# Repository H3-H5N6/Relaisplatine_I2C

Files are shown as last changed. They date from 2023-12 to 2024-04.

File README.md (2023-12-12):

# Beschreibung

8-fach Relaisplatine, die über I²C angesteuert wird. Die Relais werden dabei über eine separate Spannung versorgt.

Die I²C-Adresse muss durch entsprechende Brücken bei A0 - bis A2 ausgeält werden. Die Grundadresse des PCF 8475 ist 0x40 und de
ie des PCF 8475 ist 0x70.

Die LEDs bei den Relais leuchten, wenn die Relais in Ruhe sind. Des weiteren gibt es zwei Power-LEDs, einmal für die 5V vom I²C und einaml für die 5/12V der Relais.

Der Interrupt-Pin ist herausgezogen, aber nicht weiter beschaltet.

# Schaltplan

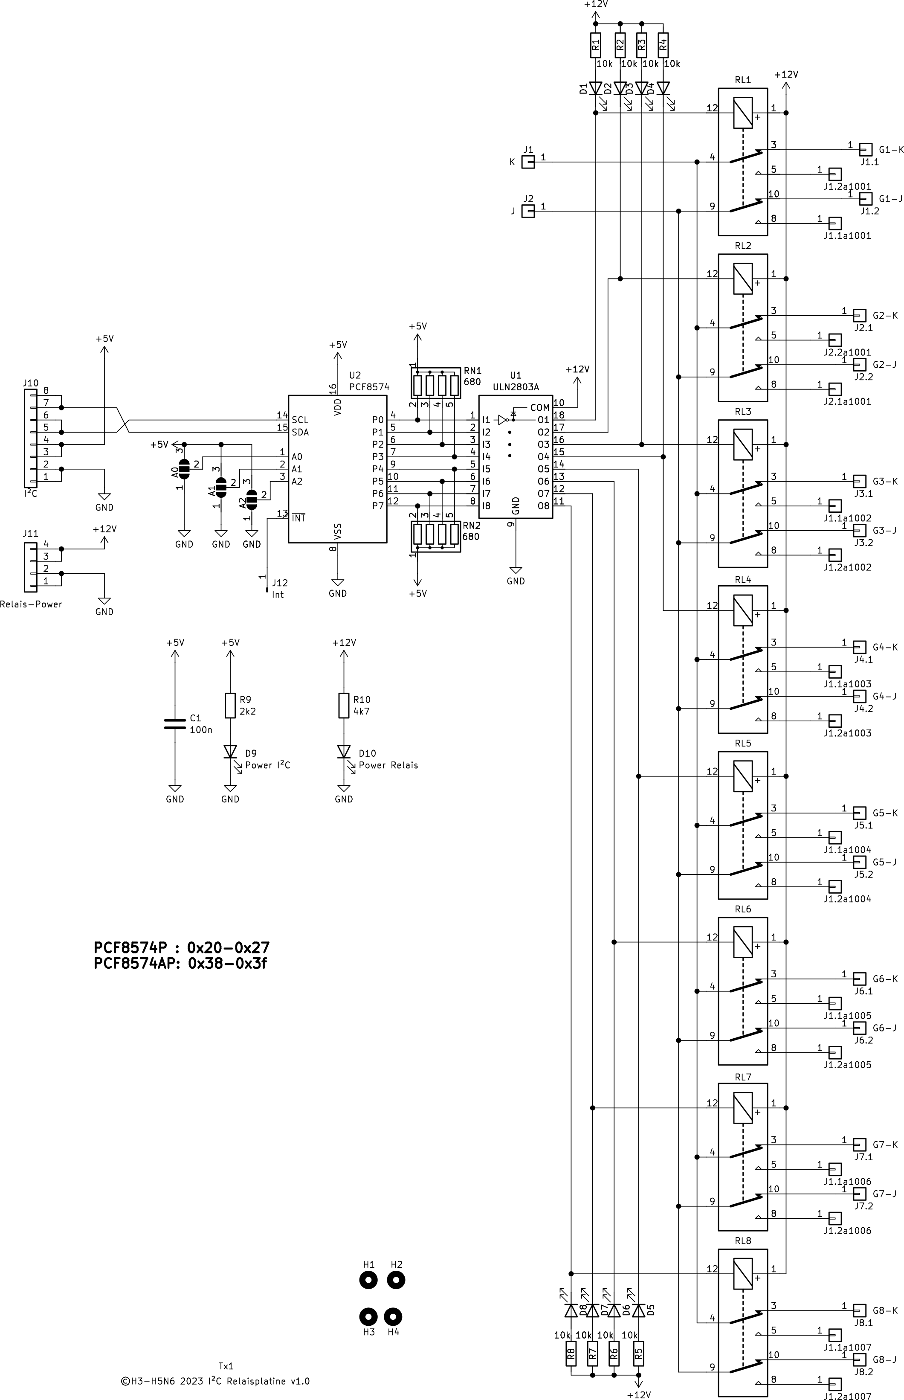
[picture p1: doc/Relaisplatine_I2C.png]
Schaltplan


# Bestückungsplan

Bestückungsplan

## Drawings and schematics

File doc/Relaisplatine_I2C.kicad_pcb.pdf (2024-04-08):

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

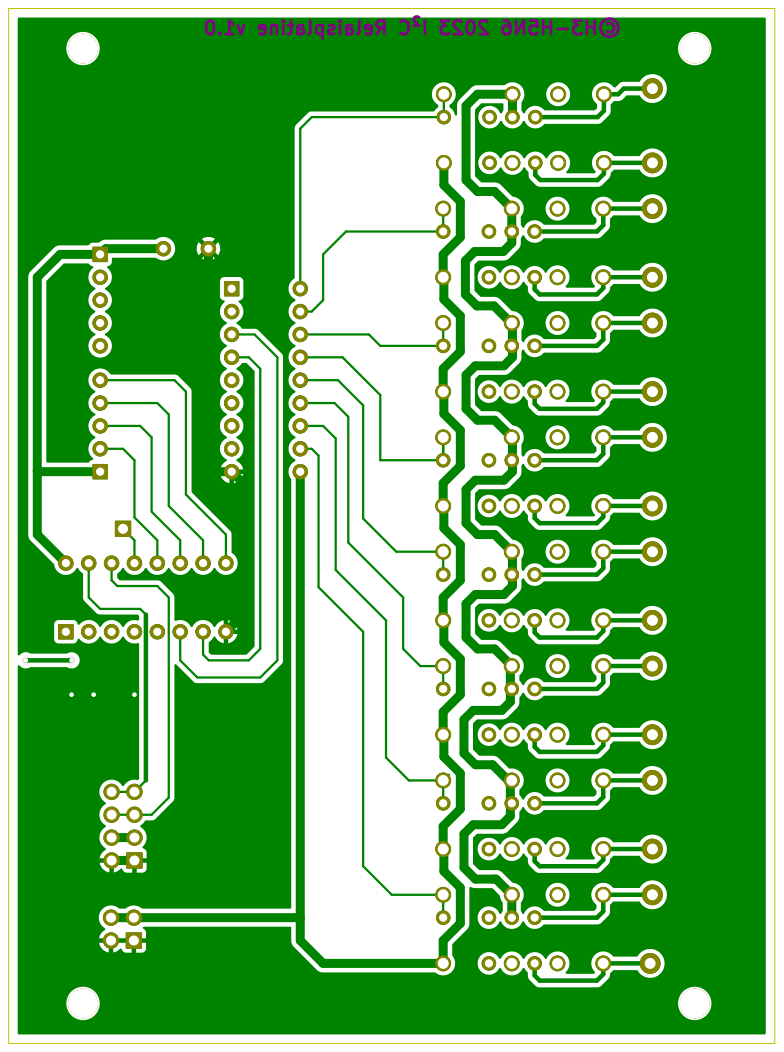
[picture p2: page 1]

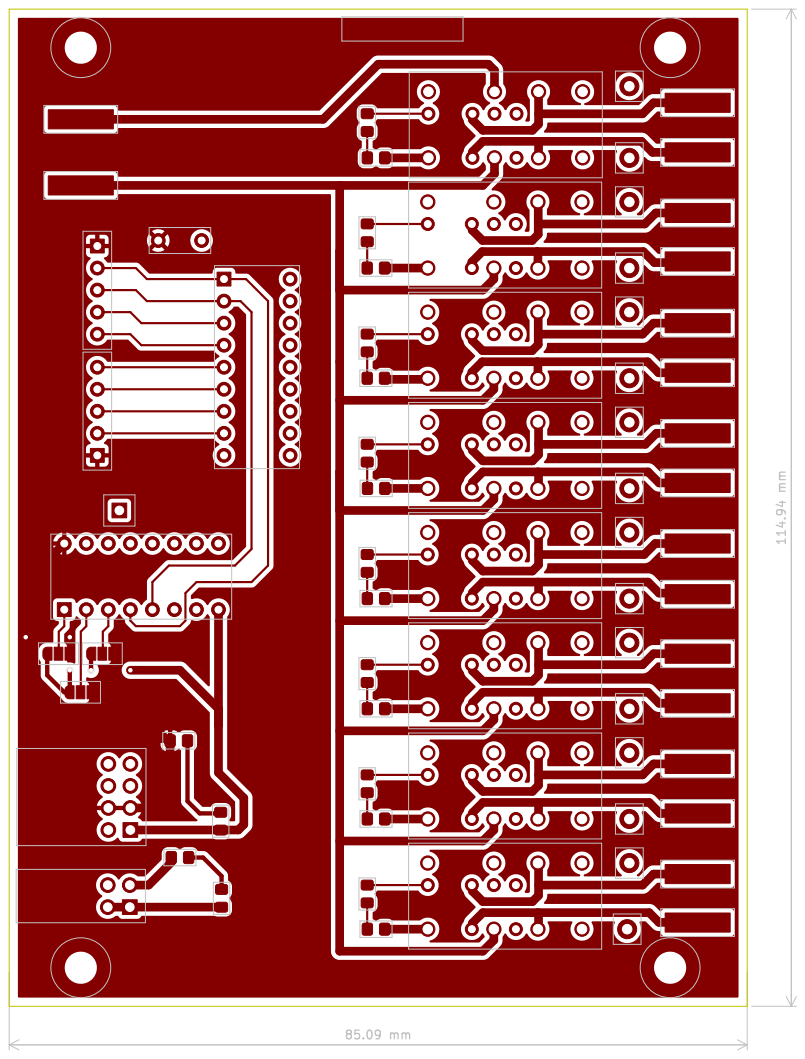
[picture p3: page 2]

# GND GND G5 G2 Relais stromlos G1 G8

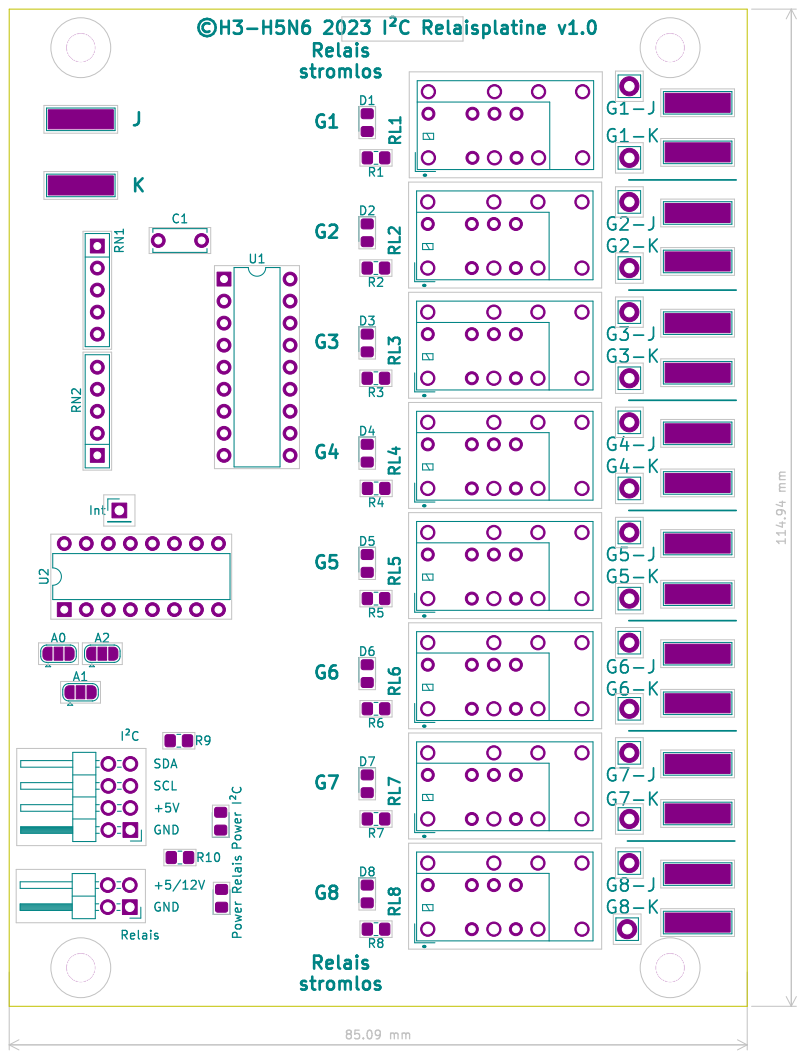
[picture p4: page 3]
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

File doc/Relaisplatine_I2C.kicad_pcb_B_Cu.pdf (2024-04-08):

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



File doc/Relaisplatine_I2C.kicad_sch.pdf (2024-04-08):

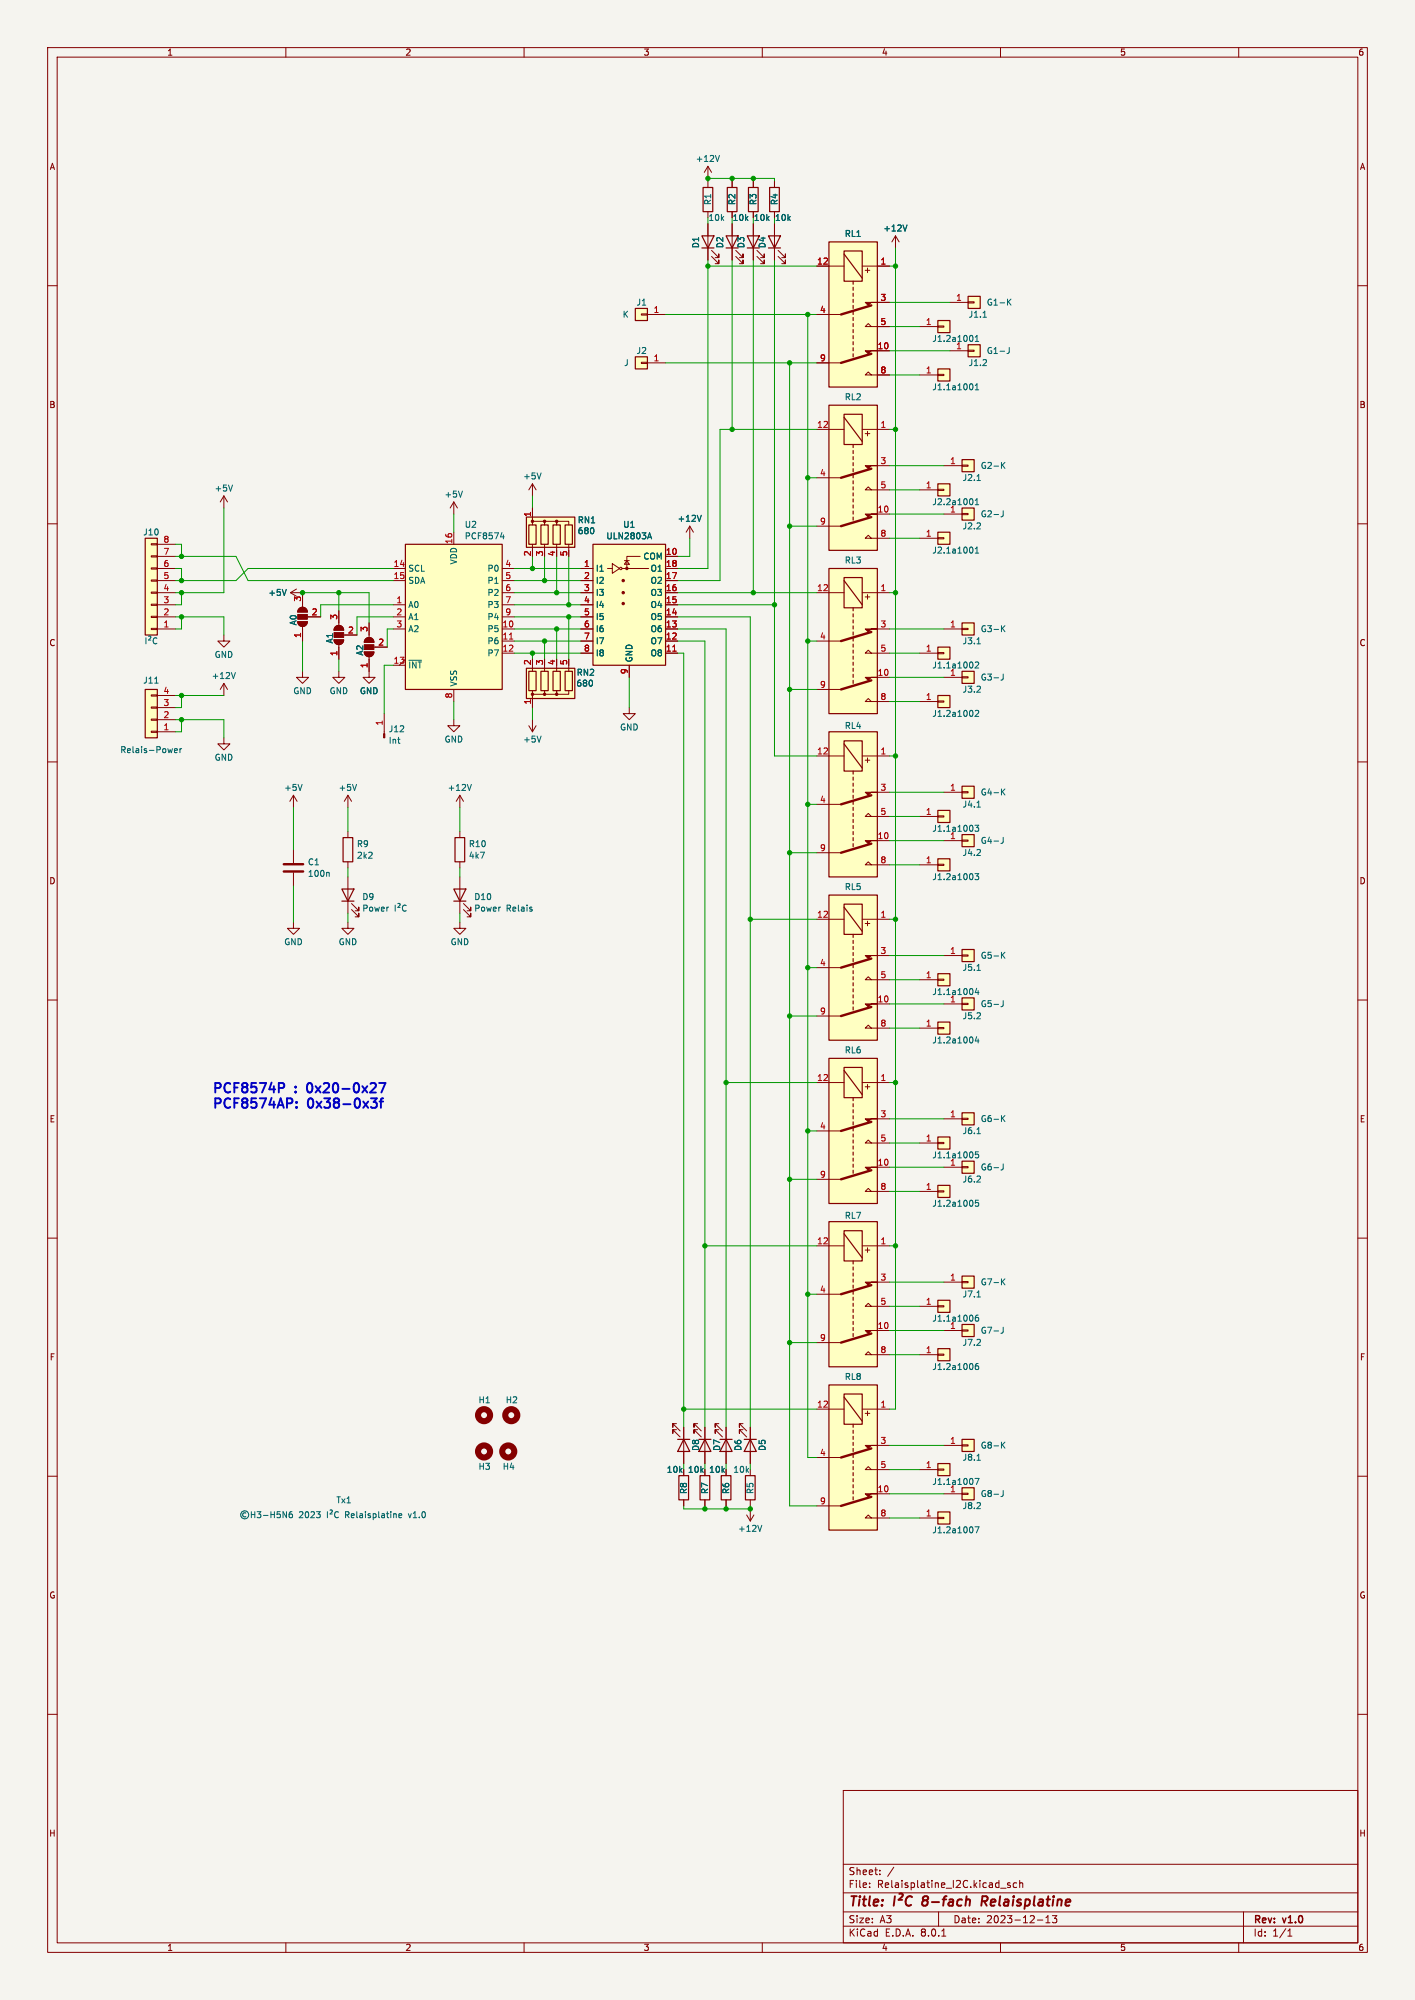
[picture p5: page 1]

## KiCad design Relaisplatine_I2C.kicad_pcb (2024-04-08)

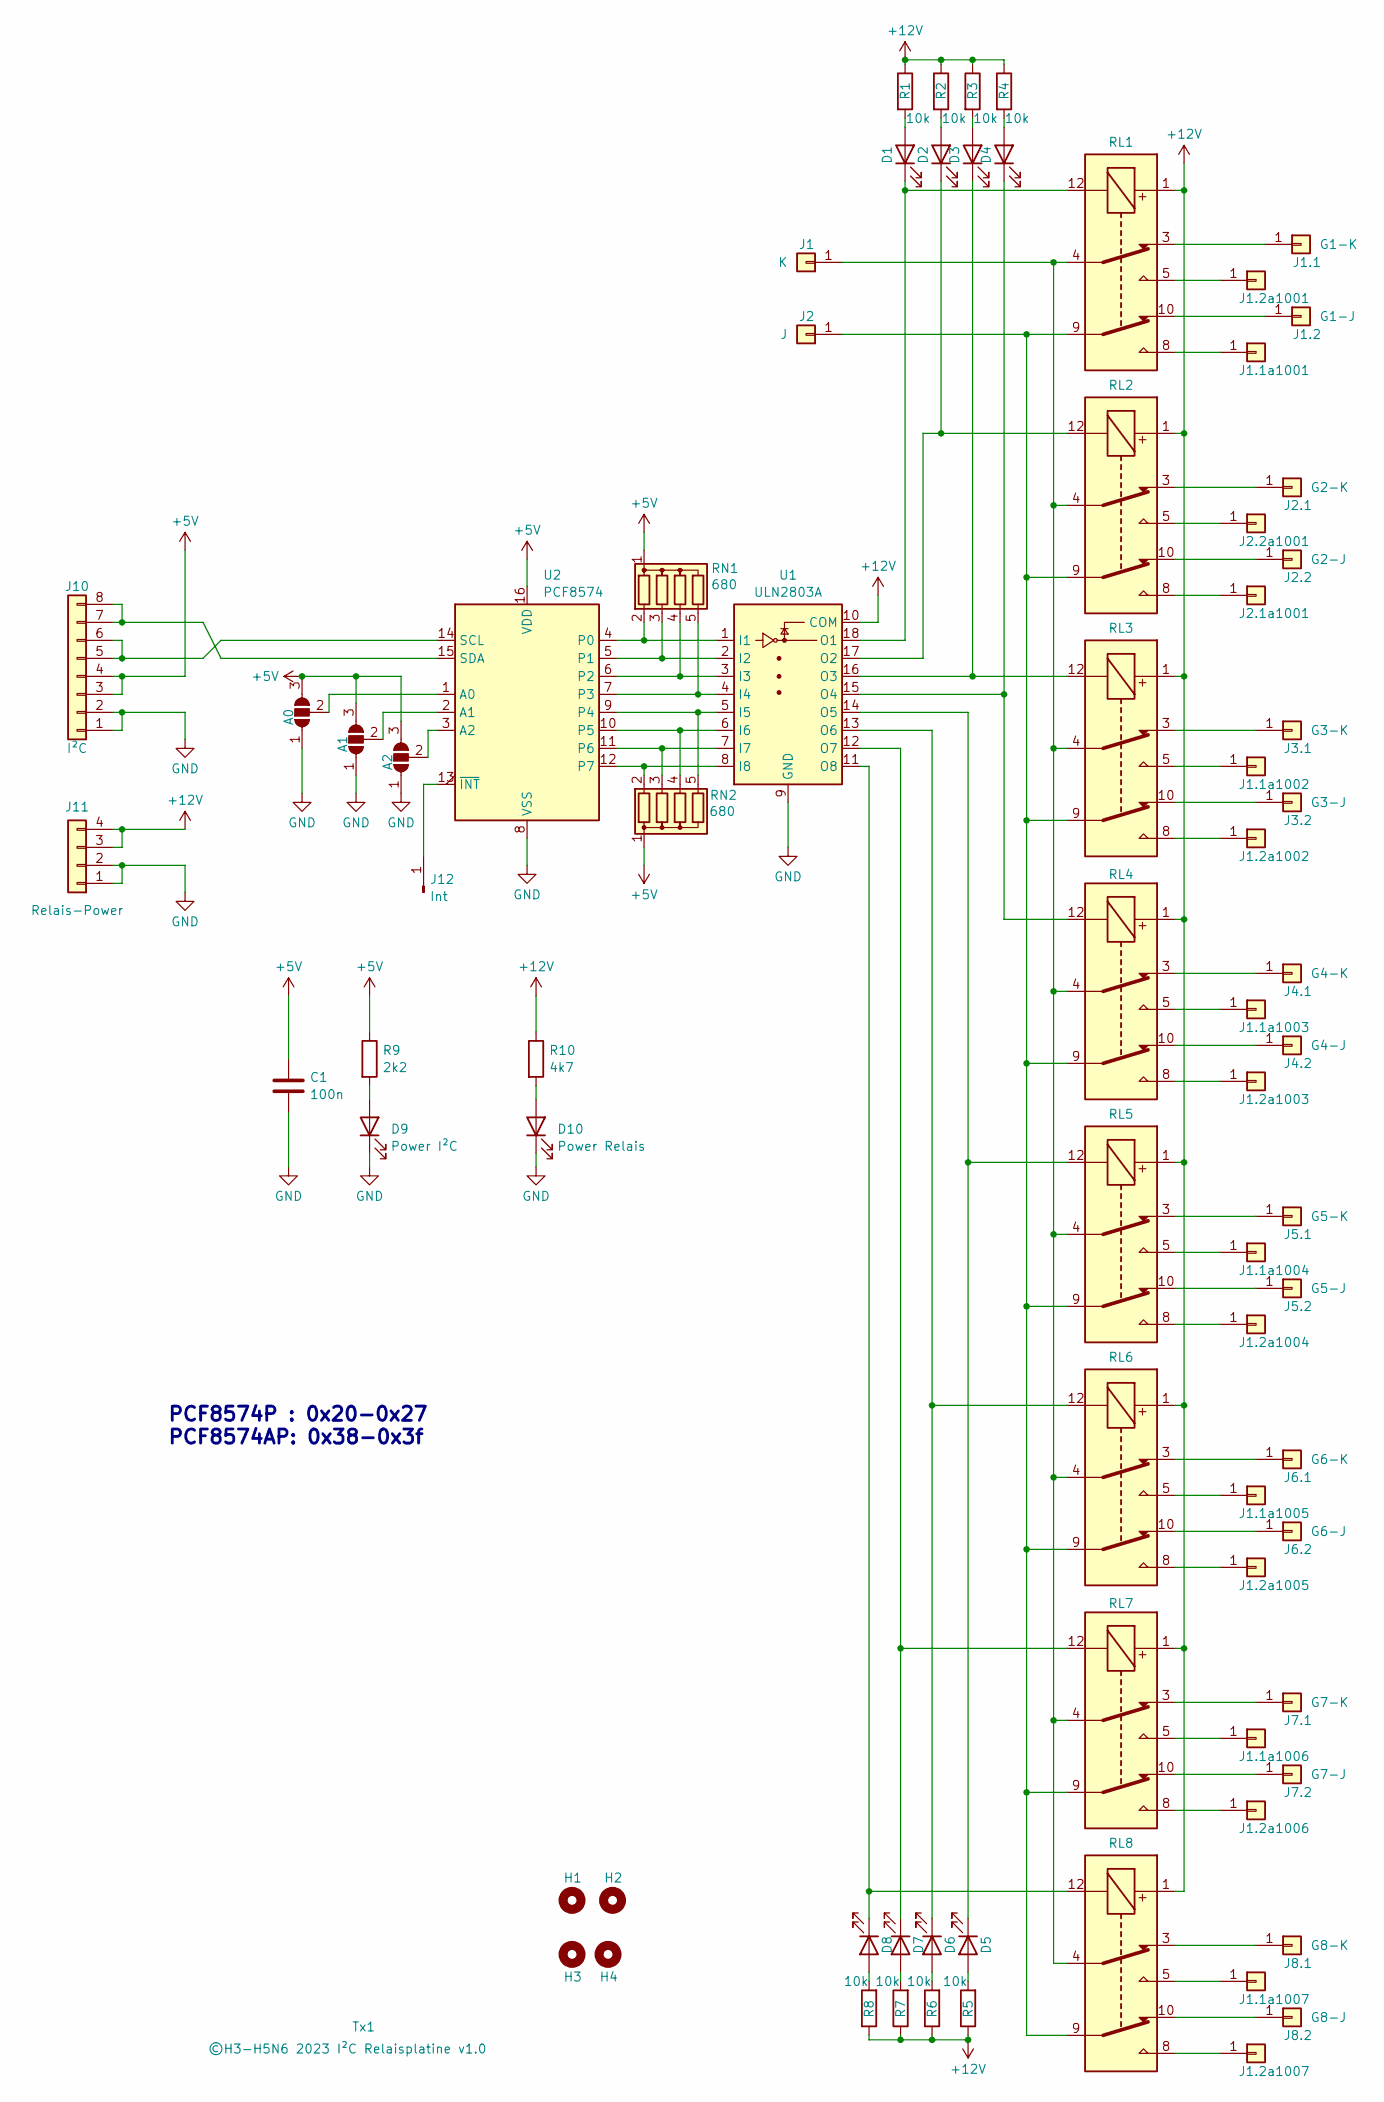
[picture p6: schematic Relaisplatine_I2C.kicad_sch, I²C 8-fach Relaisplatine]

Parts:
A0, A1, A2: SolderJumper_3_Open; SolderJumper-3_P1.3mm_Open_RoundedPad1.0x1.5mm
C1: 100n; C_Disc_D6.0mm_W2.5mm_P5.00mm
D1, D2, D3, D4, D5, D6, D7, D8: LED; LED_0805_2012Metric_Pad1.15x1.40mm_HandSolder
D9: Power I²C; LED_0805_2012Metric_Pad1.15x1.40mm_HandSolder
D10: Power Relais; LED_0805_2012Metric_Pad1.15x1.40mm_HandSolder
H1, H2, H3, H4: MountingHole; MountingHole_3.2mm_M3
J1: K; Pad_7.5x2.2mm
J1.1: G1-K; Pad_7.5x2.2mm
J1.1a1001, J1.2a1002, J1.2a1003, J1.2a1004, J1.2a1005, J1.2a1006, J1.2a1007, J2.1a1001: G1-J; Pin_D1.1mm_L8.5mm_W2.5mm_FlatFork
J1.1a1002, J1.1a1003, J1.1a1004, J1.1a1005, J1.1a1006, J1.1a1007, J1.2a1001: G1-K; Pin_D1.1mm_L8.5mm_W2.5mm_FlatFork
J1.2: G1-J; Pad_7.5x2.2mm
J2: J; Pad_7.5x2.2mm
J2.1: G2-K; Pad_7.5x2.2mm
J2.2: G2-J; Pad_7.5x2.2mm
J2.2a1001: G2-K; Pin_D1.1mm_L8.5mm_W2.5mm_FlatFork
J3.1: G3-K; Pad_7.5x2.2mm
J3.2: G3-J; Pad_7.5x2.2mm
J4.1: G4-K; Pad_7.5x2.2mm
J4.2: G4-J; Pad_7.5x2.2mm
J5.1: G5-K; Pad_7.5x2.2mm
J5.2: G5-J; Pad_7.5x2.2mm
J6.1: G6-K; Pad_7.5x2.2mm
J6.2: G6-J; Pad_7.5x2.2mm
J7.1: G7-K; Pad_7.5x2.2mm
J7.2: G7-J; Pad_7.5x2.2mm
J8.1: G8-K; Pad_7.5x2.2mm
J8.2: G8-J; Pad_7.5x2.2mm
J10: I²C; PinHeader_2x04_P2.54mm_Horizontal
J11: Relais-Power; PinHeader_2x02_P2.54mm_Horizontal
J12: Int; PinHeader_1x01_P2.54mm_Vertical
R1, R2, R3, R4, R5, R6, R7, R8: 10k; R_0805_2012Metric_Pad1.20x1.40mm_HandSolder
R9: 2k2; R_0805_2012Metric_Pad1.20x1.40mm_HandSolder
R10: 4k7; R_0805_2012Metric_Pad1.20x1.40mm_HandSolder
RL1, RL2, RL3, RL4, RL5, RL6, RL7, RL8: HFD3; HFD3+2005SD
RN1, RN2: 680; R_Array_SIP5
Tx1: ©H3-H5N6 2023 I²C Relaisplatine ${REVISION}; Text
U1: ULN2803A; DIP-18_W7.62mm
U2: PCF8574; DIP-16_W7.62mm

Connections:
+5V: A0.3 (B), A1.3 (B), A2.3 (B), C1.1, J10.3, J10.4, R9.1, RN1.1 (common), RN2.1 (common), U2.16 (VDD)
+12V: J11.3, J11.4, R1.1, R2.1, R3.1, R4.1, R5.1, R6.1, R7.1, R8.1, R10.1, RL1.1, RL2.1, RL3.1, RL4.1, RL5.1, RL6.1, RL7.1, RL8.1, U1.10 (COM)
GND: A0.1 (A), A1.1 (A), A2.1 (A), C1.2, D9.1 (K), D10.1 (K), J10.1, J10.2, J11.1, J11.2, U1.9 (GND), U2.8 (VSS)
unnamed: A0.2 (C), U2.1 (A0)
unnamed: A1.2 (C), U2.2 (A1)
unnamed: A2.2 (C), U2.3 (A2)
unnamed: D1.2 (A), R1.2
unnamed: D1.1 (K), RL1.12, U1.18 (O1)
unnamed: D2.2 (A), R2.2
unnamed: D2.1 (K), RL2.12, U1.17 (O2)
unnamed: D3.2 (A), R3.2
unnamed: D3.1 (K), RL3.12, U1.16 (O3)
unnamed: D4.2 (A), R4.2
unnamed: D4.1 (K), RL4.12, U1.15 (O4)
unnamed: D5.2 (A), R5.2
unnamed: D5.1 (K), RL5.12, U1.14 (O5)
unnamed: D6.2 (A), R6.2
unnamed: D6.1 (K), RL6.12, U1.13 (O6)
unnamed: D7.2 (A), R7.2
unnamed: D7.1 (K), RL7.12, U1.12 (O7)
unnamed: D8.2 (A), R8.2
unnamed: D8.1 (K), RL8.12, U1.11 (O8)
unnamed: D9.2 (A), R9.2
unnamed: D10.2 (A), R10.2
unnamed: J1.1, RL1.4, RL2.4, RL3.4, RL4.4, RL5.4, RL6.4, RL7.4, RL8.4
unnamed: J1.1.1, RL1.3
unnamed: J1.1a1001.1, RL1.8
unnamed: J1.1a1002.1, RL3.5
unnamed: J1.1a1003.1, RL4.5
unnamed: J1.1a1004.1, RL5.5
unnamed: J1.1a1005.1, RL6.5
unnamed: J1.1a1006.1, RL7.5
unnamed: J1.1a1007.1, RL8.5
unnamed: J1.2.1, RL1.10
unnamed: J1.2a1001.1, RL1.5
unnamed: J1.2a1002.1, RL3.8
unnamed: J1.2a1003.1, RL4.8
unnamed: J1.2a1004.1, RL5.8
unnamed: J1.2a1005.1, RL6.8
unnamed: J1.2a1006.1, RL7.8
unnamed: J1.2a1007.1, RL8.8
unnamed: J2.1, RL1.9, RL2.9, RL3.9, RL4.9, RL5.9, RL6.9, RL7.9, RL8.9
unnamed: J2.1.1, RL2.3
unnamed: J2.1a1001.1, RL2.8
unnamed: J2.2.1, RL2.10
unnamed: J2.2a1001.1, RL2.5
unnamed: J3.1.1, RL3.3
unnamed: J3.2.1, RL3.10
unnamed: J4.1.1, RL4.3
unnamed: J4.2.1, RL4.10
unnamed: J5.1.1, RL5.3
unnamed: J5.2.1, RL5.10
unnamed: J6.1.1, RL6.3
unnamed: J6.2.1, RL6.10
unnamed: J7.1.1, RL7.3
unnamed: J7.2.1, RL7.10
unnamed: J8.1.1, RL8.3
unnamed: J8.2.1, RL8.10
unnamed: J10.5, J10.6, U2.14 (SCL)
unnamed: J10.7, J10.8, U2.15 (SDA)
unnamed: J12.1, U2.13 (~INT)
unnamed: RN1.2 (R1), U1.1 (I1), U2.4 (P0)
unnamed: RN1.3 (R2), U1.2 (I2), U2.5 (P1)
unnamed: RN1.4 (R3), U1.3 (I3), U2.6 (P2)
unnamed: RN1.5 (R4), U1.4 (I4), U2.7 (P3)
unnamed: RN2.2 (R1), U1.8 (I8), U2.12 (P7)
unnamed: RN2.3 (R2), U1.7 (I7), U2.11 (P6)
unnamed: RN2.4 (R3), U1.6 (I6), U2.10 (P5)
unnamed: RN2.5 (R4), U1.5 (I5), U2.9 (P4)

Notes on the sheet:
PCF8574P : 0x20-0x27 PCF8574AP: 0x38-0x3f

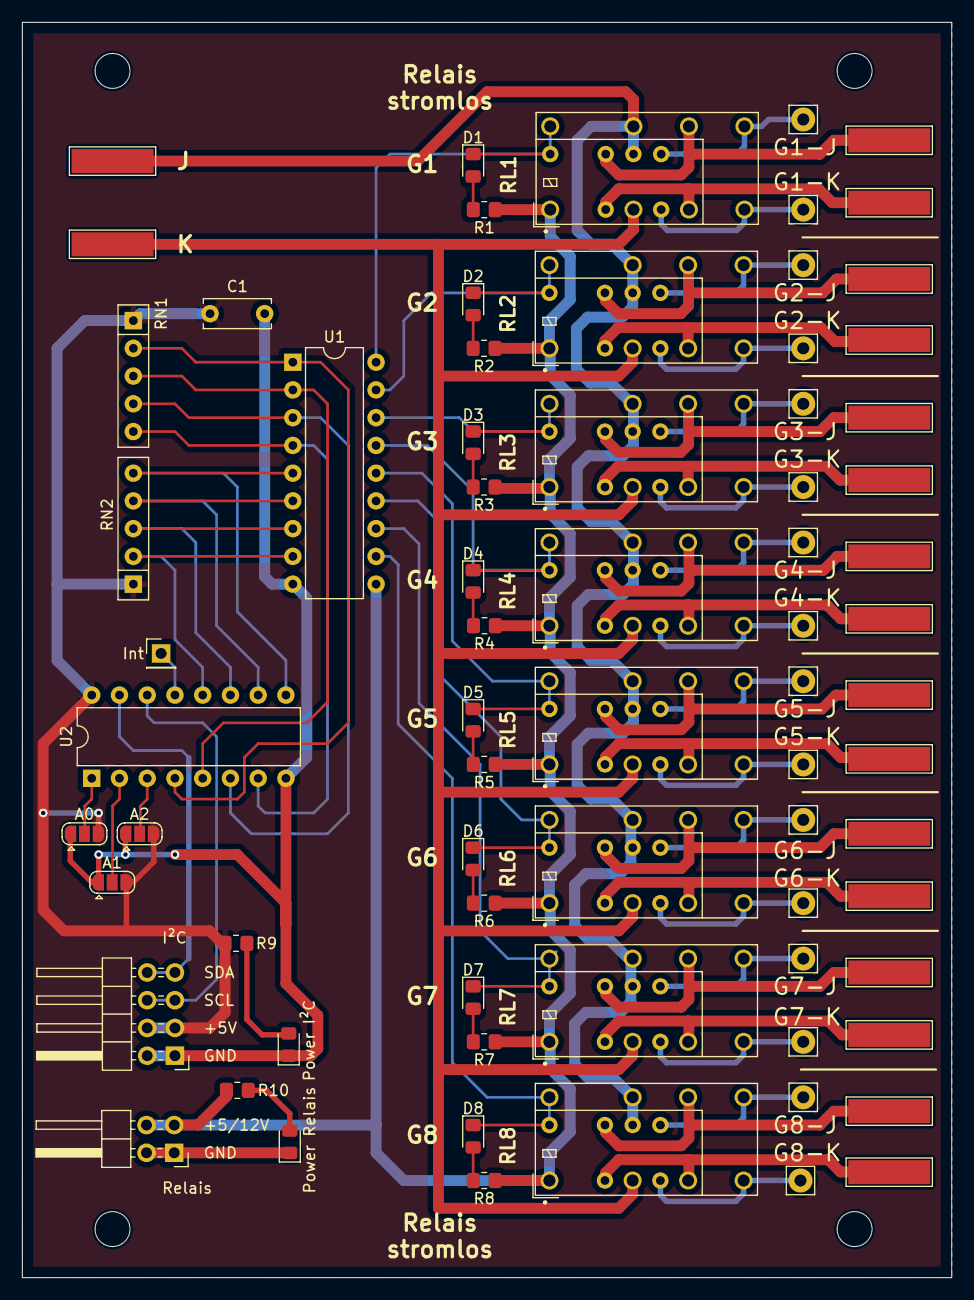
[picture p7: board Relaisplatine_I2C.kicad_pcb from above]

Board: 2 copper layers, 85.1 x 114.9 mm, 78 parts (0 on the bottom side), 69 nets.

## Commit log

2023-11-20 Readme und Schaltplan hinzugefügt
2023-11-20 Pins für A0-2 beschltet
    [Relaisplatine_I2C.kicad_pcb, Relaisplatine_I2C.kicad_sch]
2023-11-26 Script zur automatsichen Aktualisierung der PDF im doc-Ordner
2023-11-26 pdf und svg nach doc doc verschoben
2023-11-26 Unbekannte Änderungen
    [Relaisplatine_I2C.kicad_pcb, Relaisplatine_I2C.kicad_sch]
2023-11-26 schematic als pdf hinzugefügt
2023-11-27 Schema auch als png erzeugen und anzeigen
2023-11-27 Fix schematic svg
2023-12-04 Int-Pin herausgezogen und Kosmetik
    [Relaisplatine_I2C.kicad_pcb, Relaisplatine_I2C.kicad_sch]
2023-12-05 Beschriftung für Gx-J|K vergrößert
    [Relaisplatine_I2C.kicad_pcb]
2023-12-12 Power-LEDs für 5V und 12V hinzugefügt
    [Relaisplatine_I2C.kicad_pcb, Relaisplatine_I2C.kicad_sch]
2023-12-14 Revision als Feld, Widerstand der Ralais-LEDs auf 10k gesetzt
    [Relaisplatine_I2C.kicad_pcb, Relaisplatine_I2C.kicad_sch]
2023-12-15 Abstand Fläche - Plarineneand auf 1mm gesetzt
    [Relaisplatine_I2C.kicad_pcb, Relaisplatine_I2C.kicad_sch]

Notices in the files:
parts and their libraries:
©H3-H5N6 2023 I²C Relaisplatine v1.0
